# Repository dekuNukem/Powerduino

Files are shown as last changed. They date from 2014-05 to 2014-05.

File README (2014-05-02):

Powerduino - A fully programmable power strip with energy monitoring and wireless connectivity

A short introduction video: https://www.youtube.com/watch?v=ZPqnHy5OSVQ

Powerduino is a power strip that has been enhanced with a Teensy 3.1 microcontroller, RTC, current sensors, relays, WiFi module, external digital/analog IO pins, LCD, SD card, USB connector, and buttons. With an arsenal of new sensors and components, along with its open source design and Arduino compatible microcontroller, users are able to wirelessly control and monitor each socket over WiFi, observe real-time current, power and energy consumption of individual sockets, perform energy usage logging on SD card, and upload custom programs to the power strip through Arduino IDE to perform any action they want on each socket.

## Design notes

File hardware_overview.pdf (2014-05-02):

# Powerduino Hardware Overview

Xinao Wang
Adrian Beltran
Ronald Meyer
hammondmay@gmail.com

### Contents

1. Project Overview | 1 |
2. Design | 2 |
2.1 Block Diagram | 2 |
2.2 Circuit Overview | 3 |
2.2.1 Power Supply | 3 |
2.2.2 Relay Board with Current Sensor | 3 |
2.2.3 Main Board | 3 |
2.2.4 Front Panel | 4 |
2.3 Part List | 5 |
3. Project Gallery | 6 |
4. References | 8 |

### 1. Project Overview

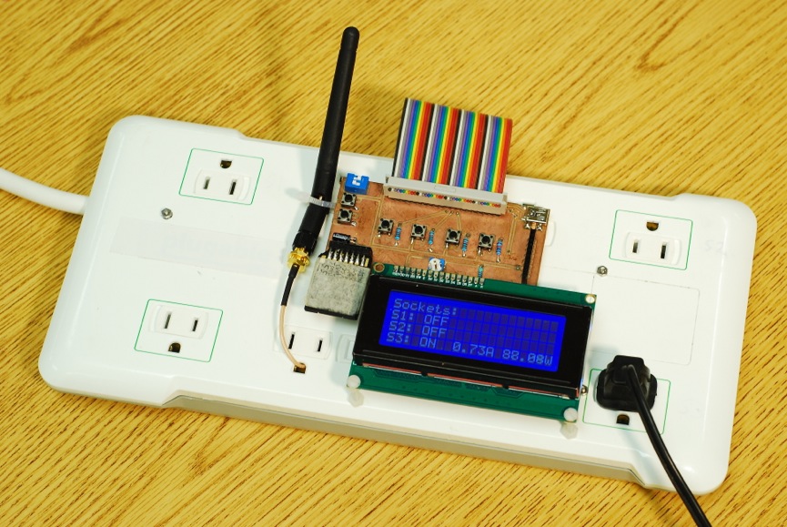
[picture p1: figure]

Powerduino is a power strip that has been enhanced with a Teensy 3.1 microcontroller, RTC, current sensors, relays, WiFi module, external digital/analog IO pins, LCD, SD card, USB connector, and buttons. With an arsenal of new sensors and components, along with its open source design and Arduino compatible microcontroller, users are able to wirelessly control and monitor each socket over WiFi, observe real-time current, power and energy consumption of individual sockets, perform energy usage logging on SD card, and upload custom programs to the power strip through Arduino IDE to perform any action they want on each socket. This enables a wide range of new applications within energy saving, safe and fast mains voltage home automation, and more.

For example, one can create an automatic lamp that turns on in the night by attaching a light sensor to one of the external pins, writing 4 lines of code, and plugging in a regular lamp in the designated socket. Similarly, with just a thermocouple, one can write a program to turn a $20 mini-oven into a reflow oven without modifying it in any way and being exposed to dangerous mains voltage. Want to turn off a socket when it has used more than 1kWh of power? Schedule a socket based on time? Limit the current that a socket can use? Implement a light dimmer right in the power strip? If you can code it, Powerduino can do it.

### 2. Design

### 2.1 Block Diagram

The construction of Powerduino is relatively straightforward, with microcontroller, WiFi module, power supply, and relay boards inside the power strip, and a front panel outside the power strip. A 2-row 40-pin ribbon cable connecting connecting them together.

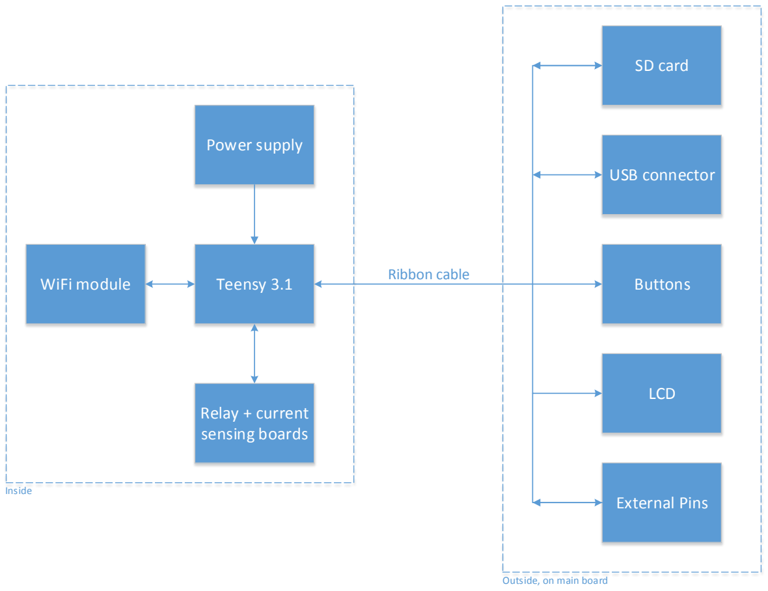
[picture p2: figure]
Teensy 3.1; Relay + current sensing boards; Power supply; WiFi module; SD card; USB connector; Buttons; LCD; External Pins; Ribbon cable; Inside; Outside, on main board

Figure 1. High-level block diagram

### 2.2 Circuit Overview

Please refer to corresponding Eagle file while reading the descriptions.

### 2.2.1 Power Supply

A simple linear power supply was designed for this project. The transformer(FP16-150) steps mains voltage down to 8V, which is then bridge rectified and regulated to provide 5V and 3.3V for various components. The half-wave of transformer’s output have also been divided down to within 3.3V, intended for microcontroller’s ADC, for zero-crossing detection. 400mA resettable fuses was used for protection. I only had 200mA fuses so I put two in parallel.

Feel free to use one of those miniature switch-mode 5V USB power supply in phone chargers, since it would be smaller than this design, and also more efficient. However you do need to implement your own 3.3V source and zero-crossing detection solution(if you need it).

### 2.2.2 Relay Board with Current Sensor

The relay board with current sensor is used to control each socket, as well as providing microcontroller with the information of how much current is passing through the relay. Two types of relay boards were designed for this project, namely solid state and mechanical.

The solid state relay was constructed with a MAC224 TRIAC controlled by a MOC3010 TRIAC driver. It provides very fast switching time, and noiseless operation. However, the TRIAC does generate a substantial amount of heat during operation, as much as around 9W when switching 10A of current. So adequate cooling is required if solid state relay are to be used continuously inside the confined space of an power strip.

The mechanical relay board is essentially the same as solid state relay board, apart from using a mechanical relay, in this case a T77S1D10-05. It produces much less heat when switching high currents compared to traic, but does produce some noise, along with slower switching times.

Both type of relay board contains a ACS712 Hall Effect current sensor to measure current. When no current is present, the output is 2.5V, while output is greater than 2.5V for current in one direction, and smaller than 2.5V in the other direction. The 0-5V output was divided down to 0-3.3V using a resistor divider for Teensy’s ADC.

When assembling the relay board, make sure to insulate vertical resistors with heat shrink tubing to prevent them from touching and shorting out.

A LED can be connected to the 2-pin header at the bottom right corner of each board, which will light up when relay is on.

### 2.2.3 Main Board

The main board houses the microcontroller, WiFi module, 3V coin battery holder for the real-time clock, and various connectors to other modules, namely power supply, relay boards, and face panel.

The reset signal is a test point on Teensy 3.1, so solder a wire on it and connect the other end to the single TEENSY_RESET header near the top right of the PCB.

To use the USB connector on the front panel for uploading program, cut a micro-usb cable, plug the micro-usb side into teensy, and connect D+, D- and Vusb wires to the headers on the PCB.

Do not use 80-wire IDE cable as a ribbon cable to connect Main Board and Front Panel, some pins in the IDE cable are electrically connected together.

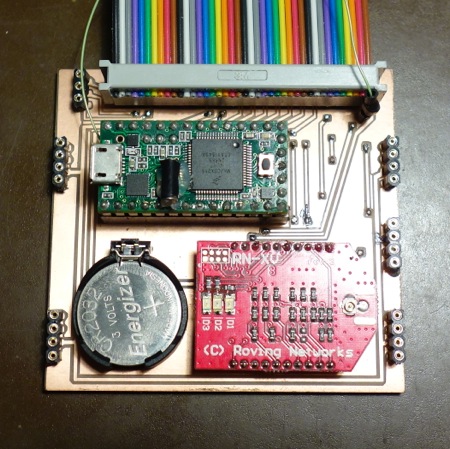
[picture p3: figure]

Figure 2. Main board

### 2.2.4 Front Panel

The front panel is located at the front of the power strip. It contains user-interface related components for the ease of use, namely LCD, buttons, SD card, external pins, mini-USB connector, as well as the connector to the main board inside.

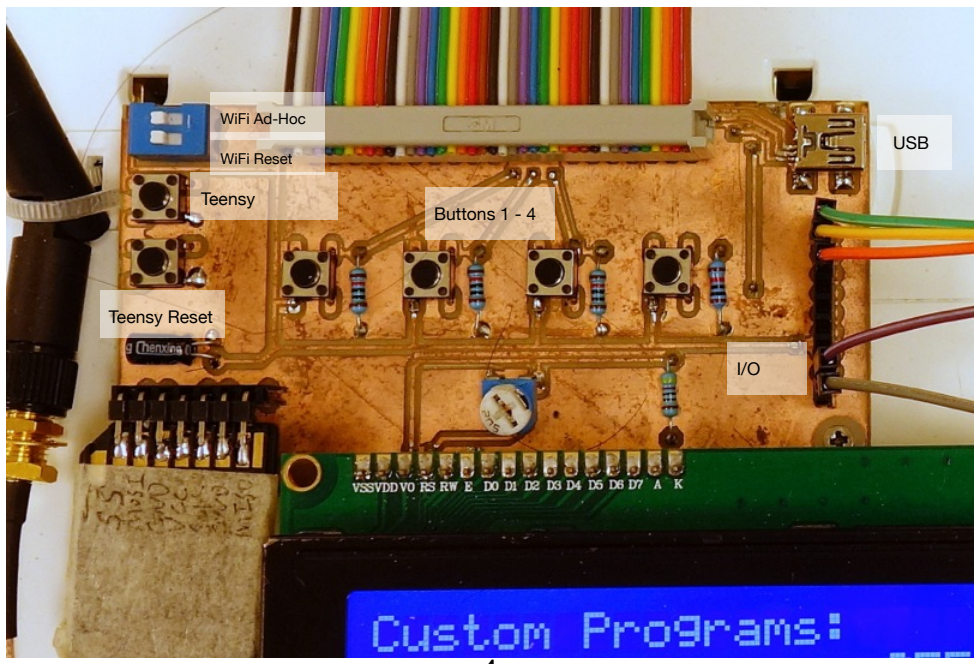
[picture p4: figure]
Buttons 1 - 4 Teensy; Teensy Reset; USB; WiFi Ad-Hoc; WiFi Reset

Figure 3. Front Panel

### 2.3 Part List

For those parts with a link to the product page, you don’t have to buy it there, just make sure the part you get is the same.

Description | Part Number | Notes
WiFi module | RN-XV WiFly | https://www.sparkfun.com/products/10822
Power strip | Plugable 12 Outlet Power Surge Protector | Purchased from Amazon (http://www.amazon.com/Plugable-Protector-Charging-Samsung-Devices/dp/B00CHRID4Y?s=electronics)
LCD | 20*4 | https://www.sparkfun.com/products/256
SD card | | Solder male pin header on Micro SD adaptor, plug into female pin header on front panel. The gold contact side facing buttons.
Microcontroller | Teensy 3.1
TRIAC | MAC224 | If you decide to use solid state relay board
TRIAC Driver | MOC3010 | If you decide to use solid state relay board
Mechanical relay | T77S1D10-05 | If you decide to use mechanical relay board
Pushbuttons | | https://www.sparkfun.com/products/97
2-Bit DIP switch | | http://i.imgur.com/cVnSq95.jpg

Assorted resistors

Assorted capacitors

Assorted pin headers

Assorted wires | | Including 40-wire ribbon cable
Resettable fuse | 500mA
Coin battery holder | | https://www.sparkfun.com/products/783
Mini-USB connector | | https://www.sparkfun.com/products/587
Transformer | TP16-150
Diode bridge | W02G
Voltage Regulators | 7805, 7833

### 3. Project Gallery

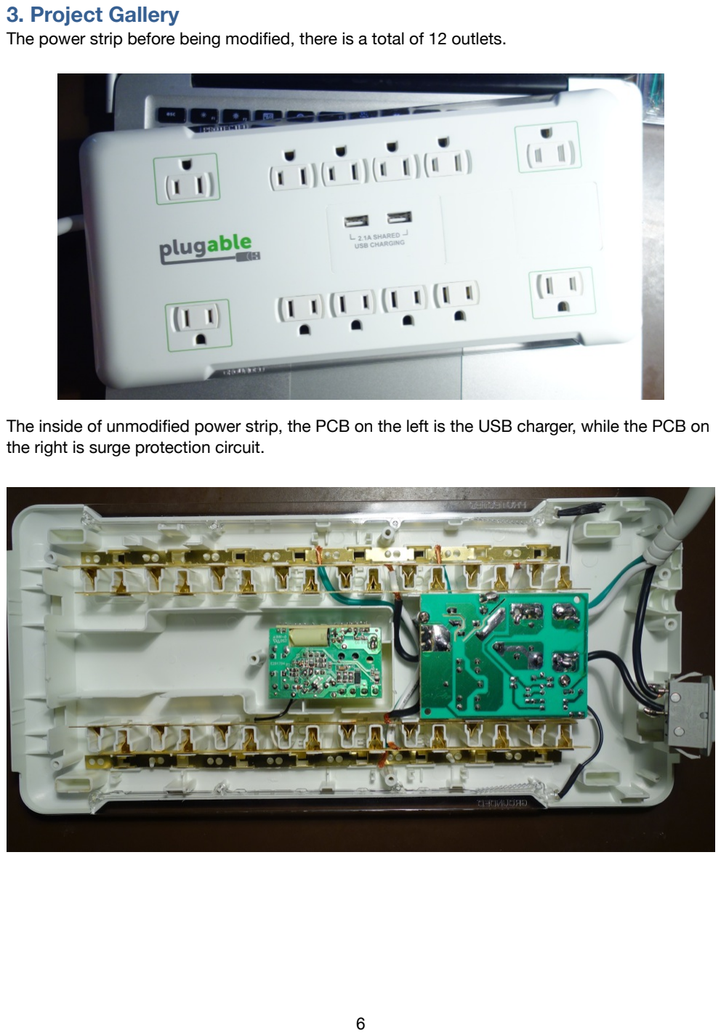
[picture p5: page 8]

The power strip before being modified, there is a total of 12 outlets.

The inside of unmodified power strip, the PCB on the left is the USB charger, while the PCB on the right is surge protection circuit.

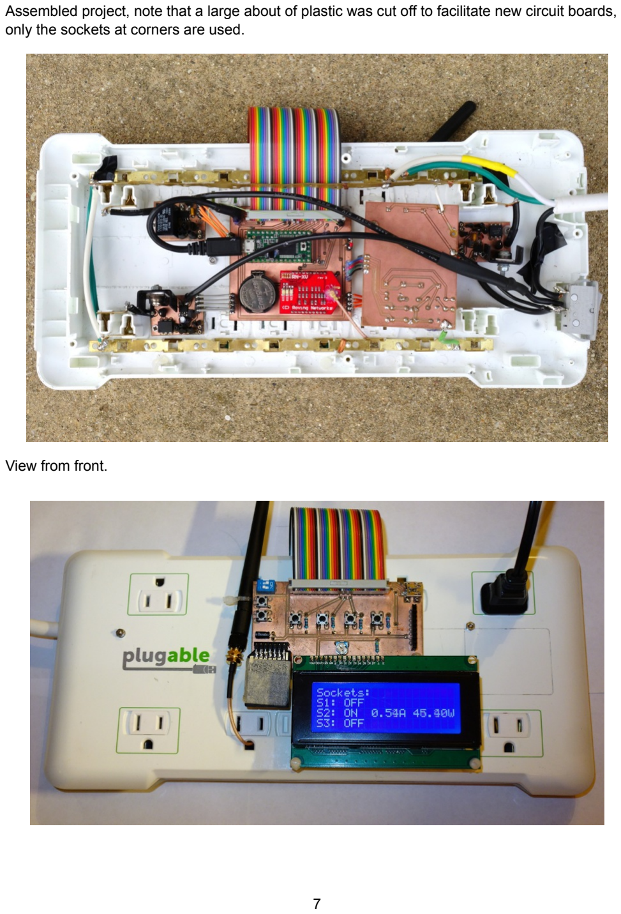
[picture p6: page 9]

Assembled project, note that a large about of plastic was cut off to facilitate new circuit boards, only the sockets at corners are used.

View from front.

### 4. References

[1] ACS712 Fully Integrated, Hall Effect-Based Linear Current Sensor with 2.1 kVRMS Voltage Isolation and a Low-Resistance Current Conductor, Allegro Microsystems, Inc., Worcester, MA, 2007.
[2] Application Note AN-3003, Applications of Non Zero Crossing TRIAC Drivers Featuring the MOC3011, Fairchild Semiconductor Corporation, 2003.

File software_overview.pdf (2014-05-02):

# Powerduino Software Overview

Xinao Wang
Adrian Beltran
Ronald Meyer
hammondmay@gmail.com

### Contents

1. Flow charts | 1 |
1.1 PC software flow chart | 1 |
1.2 Microcontroller software flow chart | 2 |
2. Functionality overview | 3 |
2.1 Communication protocol | 3 |
2.1.1 Master commands | 3 |
2.1.2 Slave commands | 3 |
2.1.3 Existing command pairs | 4 |
2.1.3.1 Set time | 4 |
2.1.3.2 Request energy usage | 4 |
2.1.3.3 Toggle socket | 4 |
2.1.3.4 Request socket status | 5 |
2.2 File structure | 5 |
2.2.1 Energy logging file | 5 |
2.2.1 Setting and states file | 6 |
2.3 Current measurement | 6 |
2.3.1 RMS current calculation | 6 |
2.3.1 Moving average smoothing | 7 |

### 1. Flow charts

### 1.1 PC software flow chart

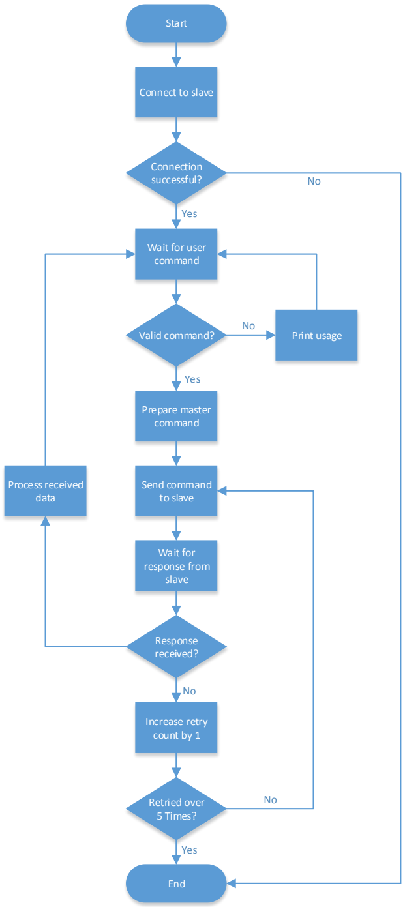
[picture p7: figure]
Start; Connect to slave; Wait for user command; Valid command?; Print usage No; Prepare master command; Yes; Send command to slave; Wait for response from slave; Connection successful?; End; Response received?; Retried over 5 Times?; Increase retry count by 1; Process received data

Figure 1. Flow chart for PC program

### 1.2 Microcontroller software flow chart

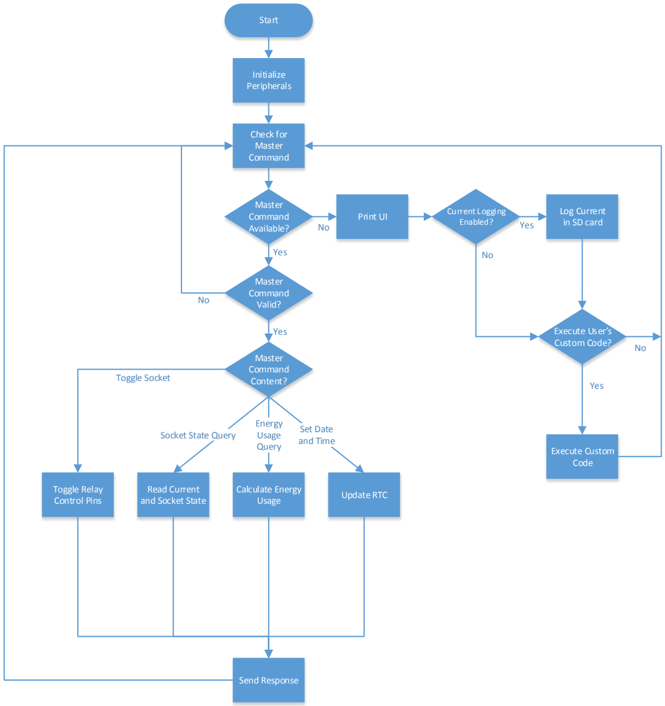
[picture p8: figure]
Start; Check for Master Command; Initialize Peripherals; Master Command Available?; Yes; Master Command Valid?; Master Command Content?; Calculate Energy Usage; Read Current; and Socket State; Update RTC Toggle Relay; Control Pins; Toggle Socket; Socket State Query; Energy Usage Query; Set Date and Time; Send Response; Log Current in SD card; Current Logging; Enabled? No; Execute User’s Custom Code?; Execute Custom Code; Print UI

Figure 2. Flow chart for microcontroller program

### 2. Functionality overview

### 2.1 Communication protocol

The communication protocol of this project is relatively straightforward. PC program send commands over WiFi network, and microcontroller receives and responds to PC command via the WiFi module over serial.

To ensure the power strip receives PC’s command, a Stop-and-wait protocol was used. Each time PC sends a command, it waits until acknowledgement from power strip is received, otherwise the command will be sent again after timeout.

### 2.1.1 Master commands

Master commands (commands generated from PC) always starts with a 2-byte header. The first byte of the header is always MASTER_COMMAND_TRANSMISSION_START, followed by the number of bytes of data to be sent to slave(power strip).

Figure 3. Master command structure

### 2.1.2 Slave commands

Slave commands (Microcontroller’s response to master commands) is structurally similar to master commands, with a 2-byte header followed by data. Except the first byte in the header is SLAVE_COMMAND_ACK.

Figure 4. Slave command structure

MASTER_COMMAND_TRANSMISSION_START

Data Length

Data

SLAVE_COMMAND_ACK

Data Length

Data

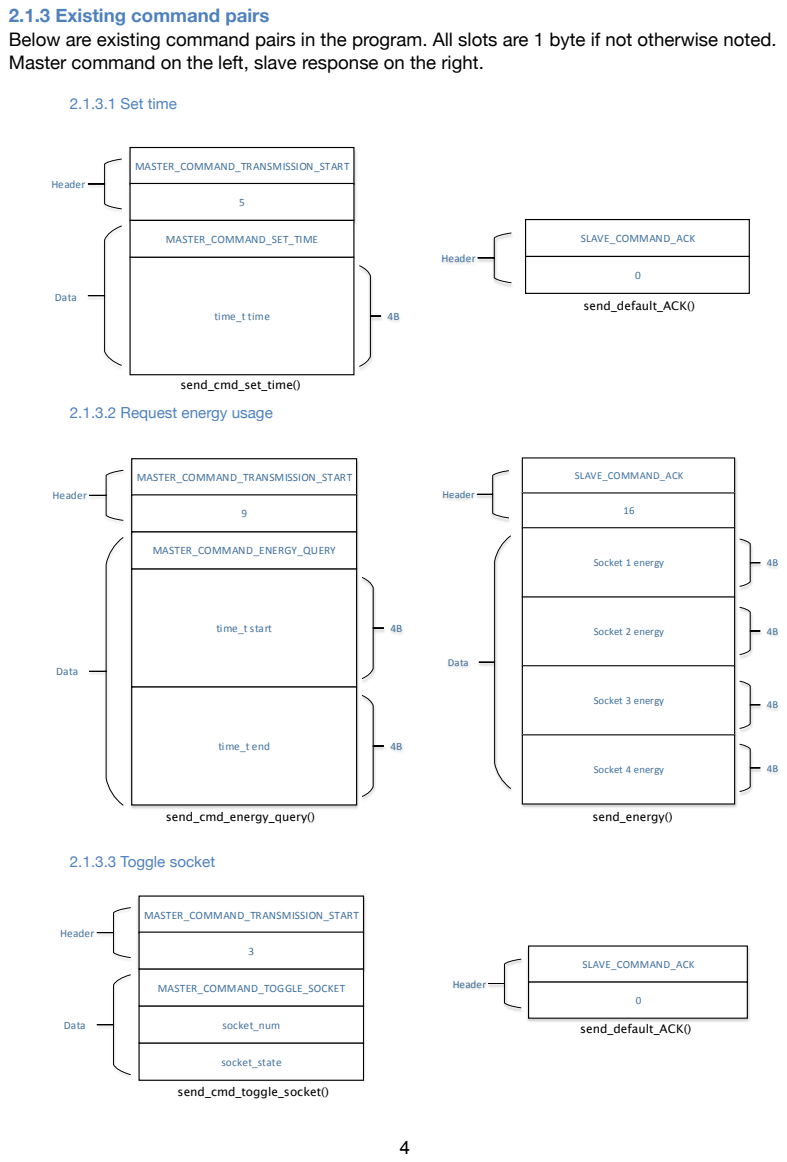
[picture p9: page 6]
2.1.3.1 Set time; 2.1.3.3 Toggle socket; Data; Header; MASTER_COMMAND_TRANSMISSION_START; MASTER_COMMAND_ENERGY_QUERY; time_t start; time_t end; SLAVE_COMMAND_ACK; _START; _QUERY; MASTER_COMMAND_TOGGLE_SOCKET; socket_num; socket_state; MASTER_COMMAND_SET_TIME; time_t time; send_cmd_set_time(); send_default_ACK(); send_cmd_energy_query(); send_energy(); send_cmd_toggle_socket()

2.1.3 Existing command pairs
Below are existing command pairs in the program. All slots are 1 byte if not otherwise noted.
Master command on the left, slave response on the right.

MASTER_COMMAND_TRANSMISSION_START

2.1.3.2 Request energy usage

Socket 1 energy

Socket 2 energy

Socket 3 energy

Socket 4 energy

2.1.3.4 Request socket status

where socket_status byte in slave response is constructed as follows:

### 2.2 File structure

The microcontroller program uses SD card for data logging and storing settings and states. The file structures are described below.

2.2.1 Energy logging file
The program stores the current reading of each socket to SD card every 10 seconds. The program will try to open a file with the name of that particular day, for example, if today is April 30th 2014, it will try to open a log file named 20140430, or create one if it doesn’t exist.

Each entry is then appended to the end of the file in little endian, with the following structure:

See append_current_log() for implementation.

Data

MASTER_COMMAND_TRANSMISSION_START

1

MASTER_COMMAND_REQUEST_SOCKET_STATUS

Header

SLAVE_COMMAND_ACK

9

socket_status

current_array_global[0]

current_array_global[1]

current_array_global[2]

current_array_global[3]

Data

Header

2B

2B

2B

2B

0 | 0 | S4 state

S3
state

S2
state

S1
state 0 | 0
7 | 0

send_cmd_request_socket_status()

send_socket_status()

Unix timestamp | S1 current | S2 current | S3 current | S4 current
4B | 2B | 2B | 2B | 2B

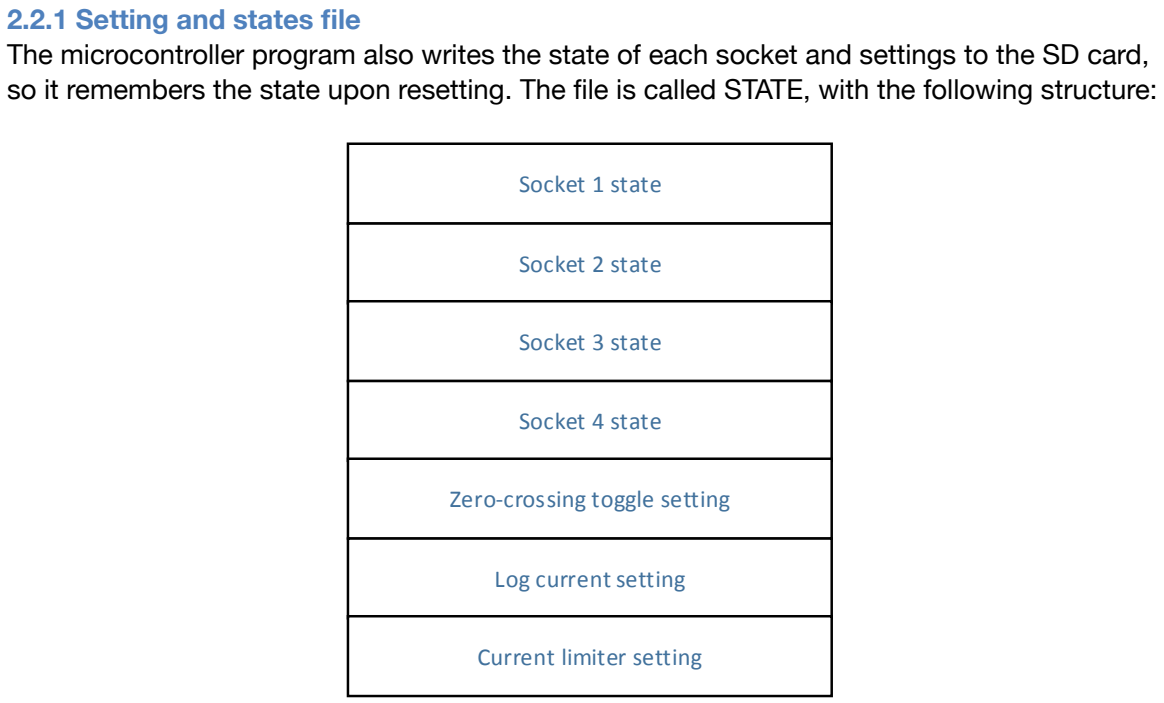
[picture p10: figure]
2.2.1 Setting and states file; Socket 1 state; Socket 2 state; Socket 3 state; Socket 4 state; Zero-crossing toggle setting; Log current setting; Current limiter setting

The microcontroller program also writes the state of each socket and settings to the SD card, so it remembers the state upon resetting. The file is called STATE, with the following structure:

Each slot is one byte, starting from the beginning of the file. See save_state() and recover_state() for implementation.

### 2.3 Current measurement

### 2.3.1 RMS current calculation

The output of current sensor is centered around 2.5V. When no current is present the output is 2.5V, output is greater than 2.5V for current in one direction, and smaller than 2.5V in the other direction. The current sensor output (0 - 5V) is divided down to 0 - 3.3V using a resistor divider. Therefore, the current sensor reading is centered around 1.6V after the division.

The resolution of Teensy's on-board ADC is 13 bits, meaning it reads 0V as 0 and 3.3V as 8192.

Each time read_current function is called, it takes 83 samples of current sensor reading in 200 microsecond interval, which is a total of 16600 microseconds, which is the period of a single 60Hz cycle (1/60 = 16.6 ms = 16666 us).

The samples are symmetrical around 1.6V, which is 8192 / 2 = 4096. To calculate RMS value, each sample is subtracted the average of entire sample array to make it center around 0, then the standard RMS method is used, taking the square root of the arithmetic mean of the squares of sample values.

The result RMS is still not current, but just the voltage reading from current sensor, to obtain current reading, a linear formula is applied, calculated from current sensor's datasheet.

I = ((4096 + RMS_value) / 8192) * 50 - 25

The resulting current is a floating number, to save space and make it easy to store on SD card and transport over serial, the float value is multiplied 1000 then stored as a 16-bit unsigned integer. For example if the result is 0.45A, 0.45 * 1000 = 450, so 450 is stored. The largest current can be stored in an int16_t is 65535 / 1000 = 65.535A, well over our current sensor’s 20A maximum rating.

This method uses quite a lot of memory and has a 17ms delay every time it’s called. Feel free to improve it, see current_reader class for implementation.

A timer interrupt fires every 0.3 seconds to call read_current function, and store the current reading in a global 4-element array, one for each socket. When a current reading is needed, the program will read the value from the array.

### 2.3.1 Moving average smoothing

However, the result of above method tend to fluctuate around the true reading, in order to achieve a smoother readout, each new current reading is taken average with 9 previous readings.

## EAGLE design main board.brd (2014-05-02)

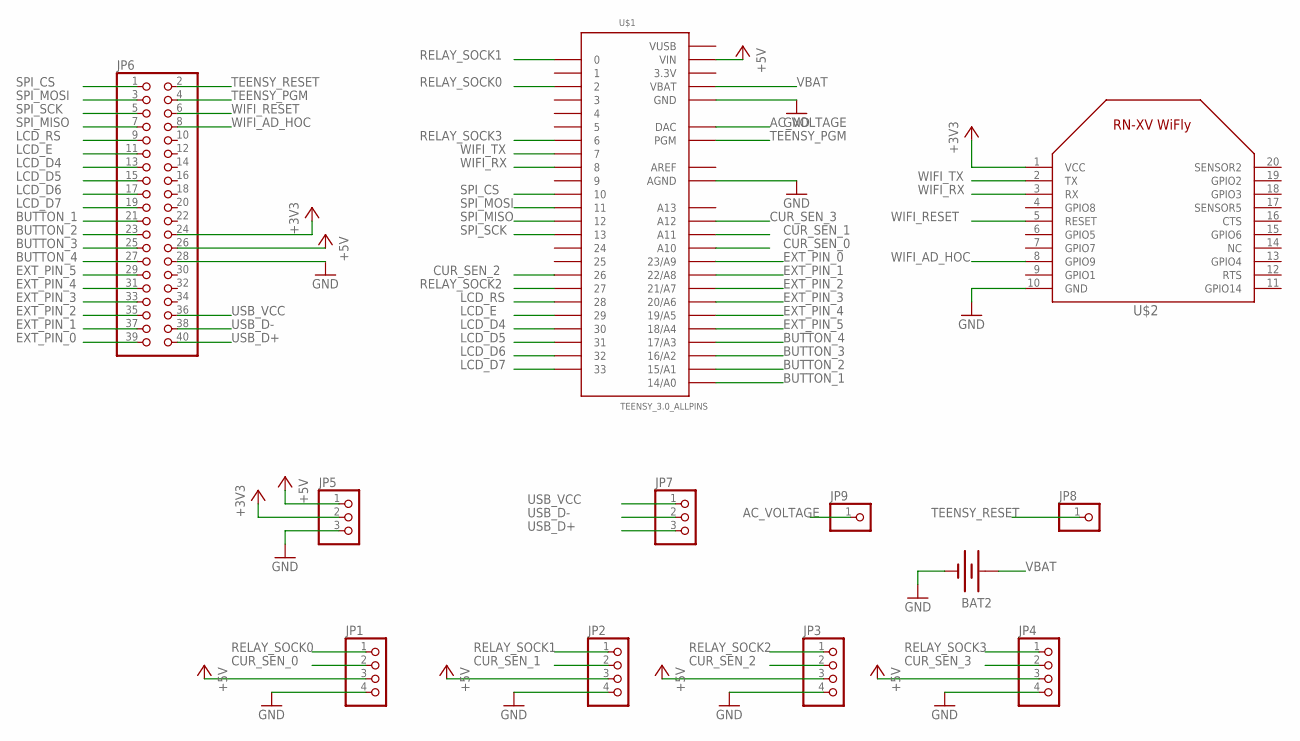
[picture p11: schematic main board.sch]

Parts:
BAT2: BATTERY20PTH; BATTCOM_20MM_PTH
JP1, JP2, JP3, JP4: PINHD-1X4/90; 1X04/90
JP5: PINHD-1X3/90; 1X03/90
JP6: PINHD-2X20; 2X20
JP7: PINHD-1X3; 1X03
JP8, JP9: PINHD-1X1; 1X01
U$1: TEENSY_3.0_ALLPINS
U$2: XBEEWIFLY; XBEE

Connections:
3.3V: U$1.3.3V, U$1.3.3V1 (3.3V), U$1.3.3V2 (3.3V)
+3V3: JP5.2, JP6.24, U$2.1 (VCC)
+5V: JP1.3, JP2.3, JP3.3, JP4.3, JP5.1, JP6.26, U$1.VIN
AC_VOLTAGE: JP9.1, U$1.RESET (DAC)
AREF: U$1.AREF
BUTTON_1: JP6.21, U$1.14/A0
BUTTON_2: JP6.23, U$1.15/A1
BUTTON_3: JP6.25, U$1.16/A2
BUTTON_4: JP6.27, U$1.17/A3
CUR_SEN_0: JP1.2, U$1.A10
CUR_SEN_1: JP2.2, U$1.A11
CUR_SEN_2: JP3.2, U$1.26
CUR_SEN_3: JP4.2, U$1.A12
EXT_PIN_0: JP6.39, U$1.23/A9
EXT_PIN_1: JP6.37, U$1.22/A8
EXT_PIN_2: JP6.35, U$1.21/A7
EXT_PIN_3: JP6.33, U$1.20/A6
EXT_PIN_4: JP6.31, U$1.19/A5
EXT_PIN_5: JP6.29, U$1.18/A4
GND: BAT2.2 (-), JP1.4, JP2.4, JP3.4, JP4.4, JP5.3, JP6.28, U$1.AGND, U$1.GND, U$1.GND1 (GND), U$1.GND2 (GND), U$2.10 (GND)
LCD_D4: JP6.13, U$1.30
LCD_D5: JP6.15, U$1.31
LCD_D6: JP6.17, U$1.32
LCD_D7: JP6.19, U$1.33
LCD_E: JP6.11, U$1.29
LCD_RS: JP6.9, U$1.28
RELAY_SOCK0: JP1.1, U$1.2
RELAY_SOCK1: JP2.1, U$1.0
RELAY_SOCK2: JP3.1, U$1.27
RELAY_SOCK3: JP4.1, U$1.6
SPI_CS: JP6.1, U$1.10
SPI_MISO: JP6.7, U$1.12
SPI_MOSI: JP6.3, U$1.11
SPI_SCK: JP6.5, U$1.13
TEENSY_PGM: JP6.4, U$1.PGM
TEENSY_RESET: JP6.2, JP8.1
USB_D+: JP6.40, JP7.3
USB_D-: JP6.38, JP7.2
USB_VCC: JP6.36, JP7.1
VBAT: BAT2.1 (+), U$1.VBAT
VUSB: U$1.VUSB
WIFI_AD_HOC: JP6.8, U$2.8 (GPIO9)
WIFI_RESET: JP6.6, U$2.5 (RESET)
WIFI_RX: U$1.8, U$2.3 (RX)
WIFI_TX: U$1.7, U$2.2 (TX)

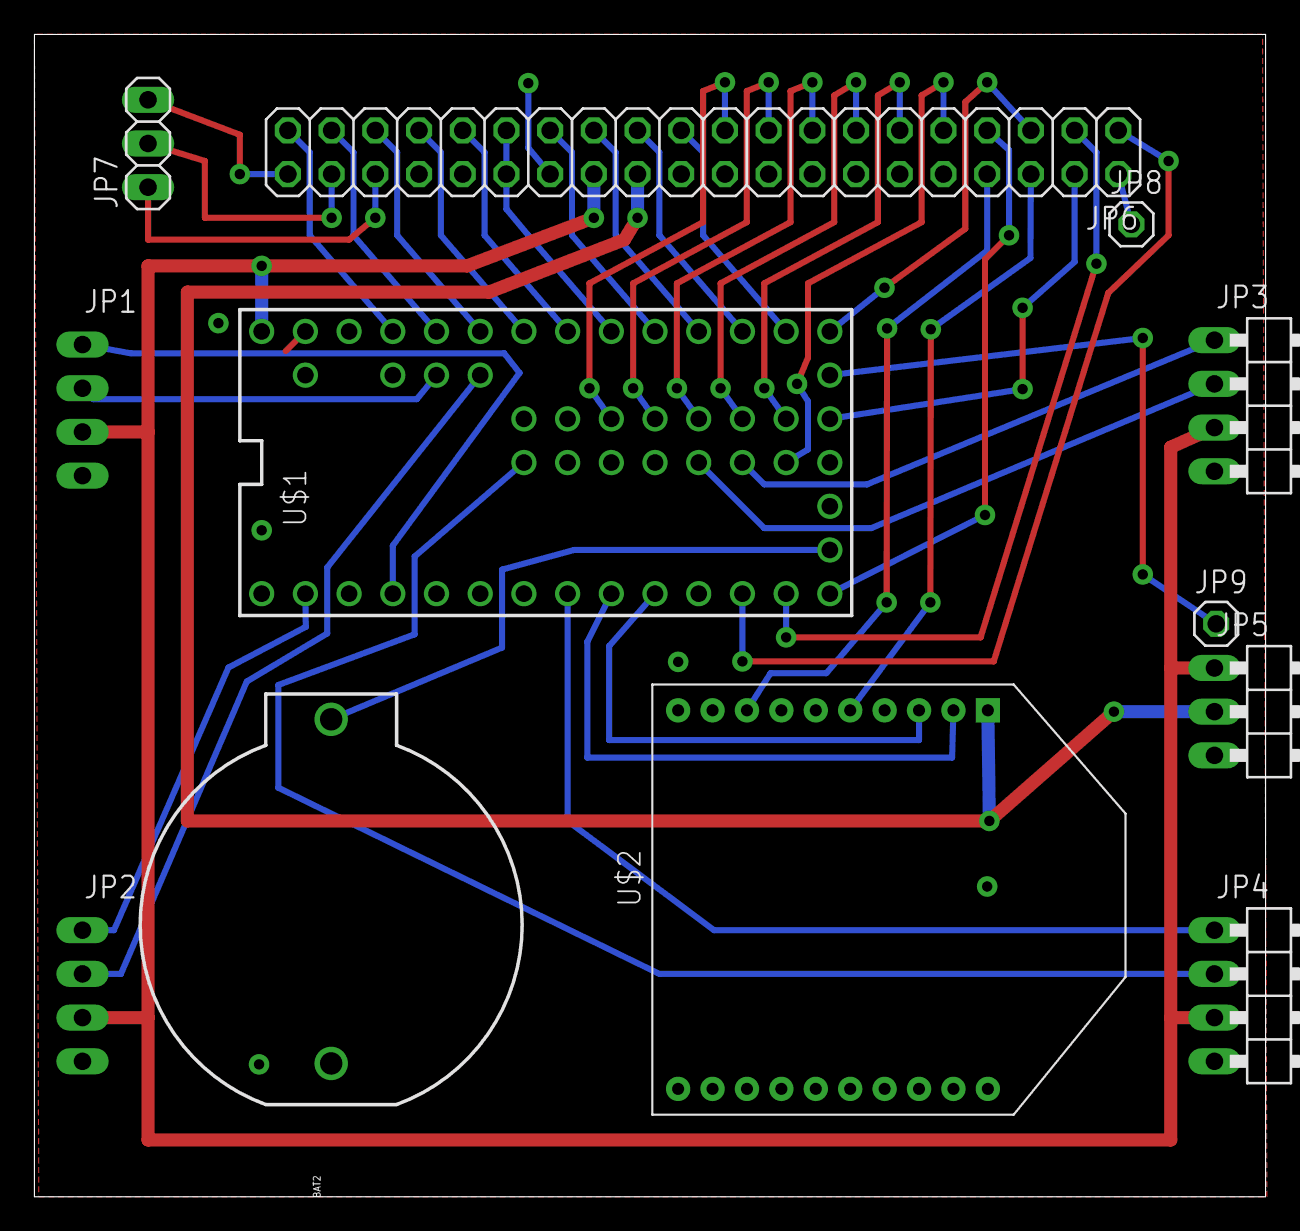
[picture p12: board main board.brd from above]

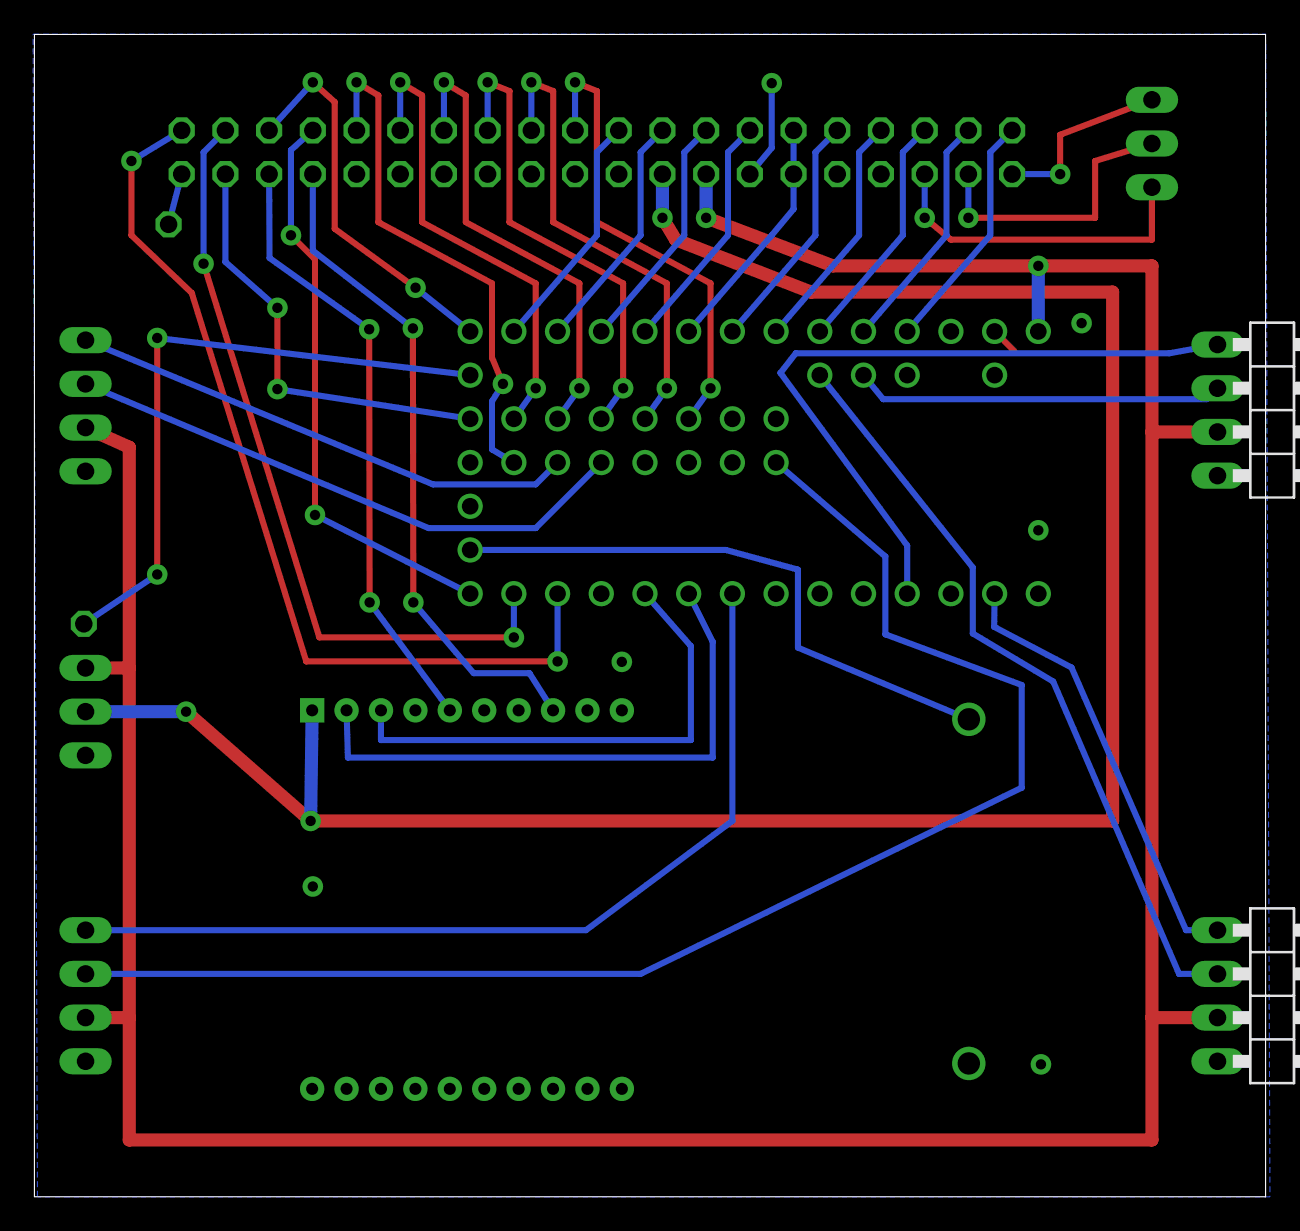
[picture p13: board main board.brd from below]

Board: 2 copper layers, 71.6 x 67.6 mm, 12 parts (2 on the bottom side), 43 nets.

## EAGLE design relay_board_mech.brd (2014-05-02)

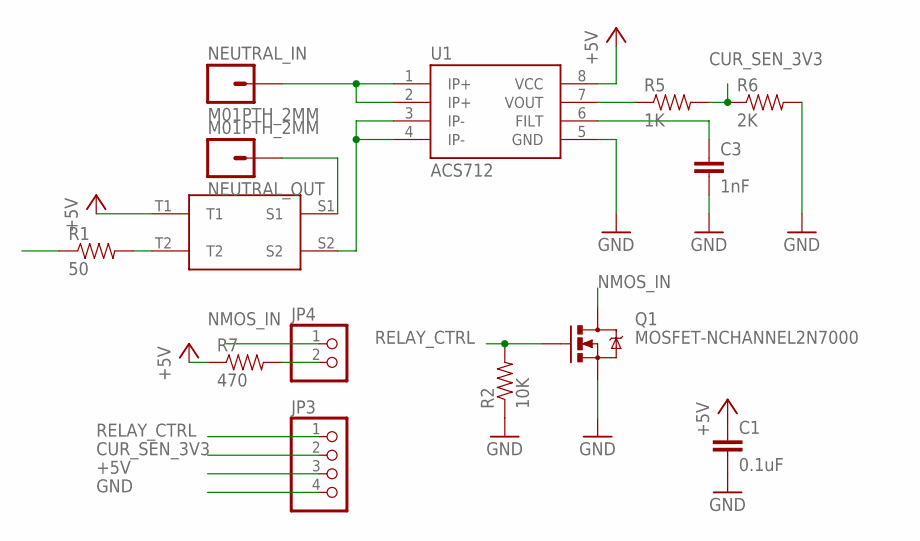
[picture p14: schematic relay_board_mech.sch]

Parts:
C1: 0.1uF; CAP-PTH-SMALLEZ
C3: 1nF; CAP-PTH-SMALLEZ
JP3: PINHD-1X4; 1X04
JP4: PINHD-1X2; 1X02
NEUTRAL_IN: M01PTH_2MM; 1X01_2MM
NEUTRAL_OUT: M01PTH_2MM; 1X01_2MM
Q1: MOSFET-NCHANNEL2N7000; TO-92
R1: 50; AXIAL-0.1
R2: 10K; AXIAL-0.1
R5: 1K; AXIAL-0.1
R6: 2K; AXIAL-0.1
R7: 470; AXIAL-0.1
U1: ACS712; SO08
U$1: T77S1D10-05

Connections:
+5V: C1.1, JP3.3, R7.P$1 (1), U1.8 (VCC), U$1.T1
CUR_SEN_3V3: JP3.2, R5.P$2 (2), R6.P$1 (1)
CUR_SEN_5V: R5.P$1 (1), U1.7 (VOUT)
GND: C1.2, C3.2, JP3.4, Q1.1 (S), R2.P$1 (1), R6.P$2 (2), U1.5 (GND)
unnamed: NEUTRAL_OUT.1, U$1.S1
unnamed: R1.P$2 (2), U$1.T2
unnamed: C3.1, U1.6 (FILT)
unnamed: NEUTRAL_IN.1, U1.1 (IP+), U1.2 (IP+)
unnamed: JP4.2, R7.P$2 (2)
unnamed: U1.3 (IP-), U1.4 (IP-), U$1.S2
NMOS_IN: JP4.1, Q1.3 (D), R1.P$1 (1)
RELAY_CTRL: JP3.1, Q1.2 (G), R2.P$2 (2)

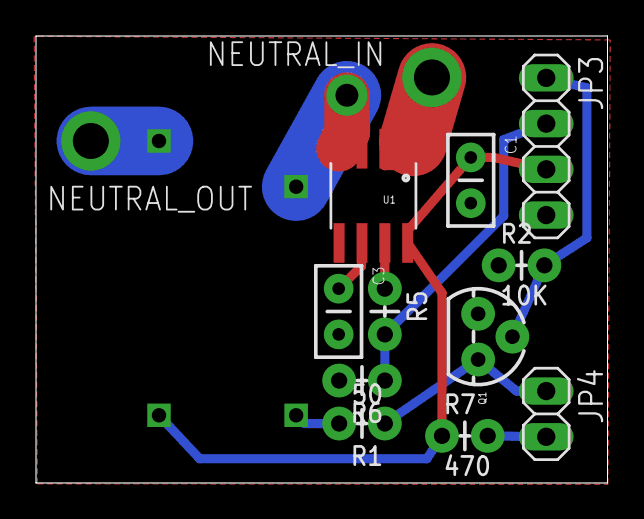
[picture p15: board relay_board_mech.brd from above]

Board: 2 copper layers, 31.8 x 24.8 mm, 14 parts (0 on the bottom side), 12 nets.

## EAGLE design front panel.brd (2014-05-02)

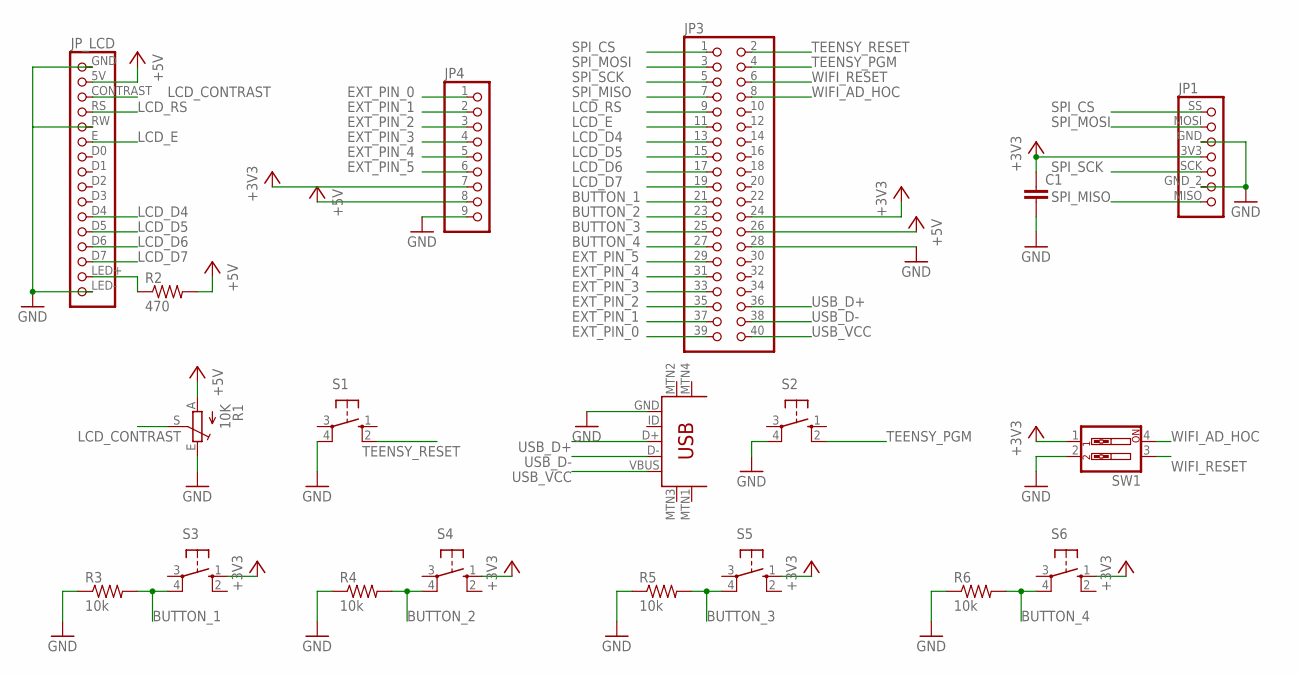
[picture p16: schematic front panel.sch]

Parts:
C1: 0.1UF-50V-20%(PTH)KIT-EZ; CAP-PTH-SMALL-KIT
JP1: PINHD-1X7; 1X07
JP3: PINHD-2X20; 2X20
JP4: PINHD-1X9; 1X09
JP_LCD: PINHD-1X16; 1X16
R1: 10K; CA6V
R2: 470; 0207/10
R3, R4, R5, R6: 10k; 0207/10
S1, S2, S3, S4, S5, S6: 10-XX; B3F-10XX
SW1: SW_DIP-2; EDG-02
U$1: USB-MINIB-5PIN; USB-MINIB

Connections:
+3V3: C1.1, JP1.3V3 (4), JP3.24, JP4.7, S3.1 (S), S4.1 (S), S5.1 (S), S6.1 (S), SW1.1
+5V: JP3.26, JP4.8, JP_LCD.5V, R1.A, R2.2
BUTTON_1: JP3.21, R3.2, S3.4 (P1)
BUTTON_2: JP3.23, R4.2, S4.4 (P1)
BUTTON_3: JP3.25, R5.2, S5.4 (P1)
BUTTON_4: JP3.27, R6.2, S6.4 (P1)
EXT_PIN_0: JP3.39, JP4.1
EXT_PIN_1: JP3.37, JP4.2
EXT_PIN_2: JP3.35, JP4.3
EXT_PIN_3: JP3.33, JP4.4
EXT_PIN_4: JP3.31, JP4.5
EXT_PIN_5: JP3.29, JP4.6
GND: C1.2, JP1.GND (3), JP1.GND_2 (6), JP3.28, JP4.9, JP_LCD.GND, JP_LCD.LED-, JP_LCD.RW, R1.E, R3.1, R4.1, R5.1, R6.1, S1.4 (P1), S2.4 (P1), SW1.2, U$1.GND
LCD_CONTRAST: JP_LCD.CONTRAST, R1.S
LCD_D4: JP3.13, JP_LCD.D4
LCD_D5: JP3.15, JP_LCD.D5
LCD_D6: JP3.17, JP_LCD.D6
LCD_D7: JP3.19, JP_LCD.D7
LCD_E: JP3.11, JP_LCD.E
LCD_RS: JP3.9, JP_LCD.RS
unnamed: JP_LCD.LED+, R2.1
SPI_CS: JP1.SS (1), JP3.1
SPI_MISO: JP1.MISO (7), JP3.7
SPI_MOSI: JP1.MOSI (2), JP3.3
SPI_SCK: JP1.SCK (5), JP3.5
TEENSY_PGM: JP3.4, S2.2 (S1)
TEENSY_RESET: JP3.2, S1.2 (S1)
USB_D+: JP3.36, U$1.D+
USB_D-: JP3.38, U$1.D-
USB_VCC: JP3.40, U$1.VBUS
WIFI_AD_HOC: JP3.8, SW1.4
WIFI_RESET: JP3.6, SW1.3

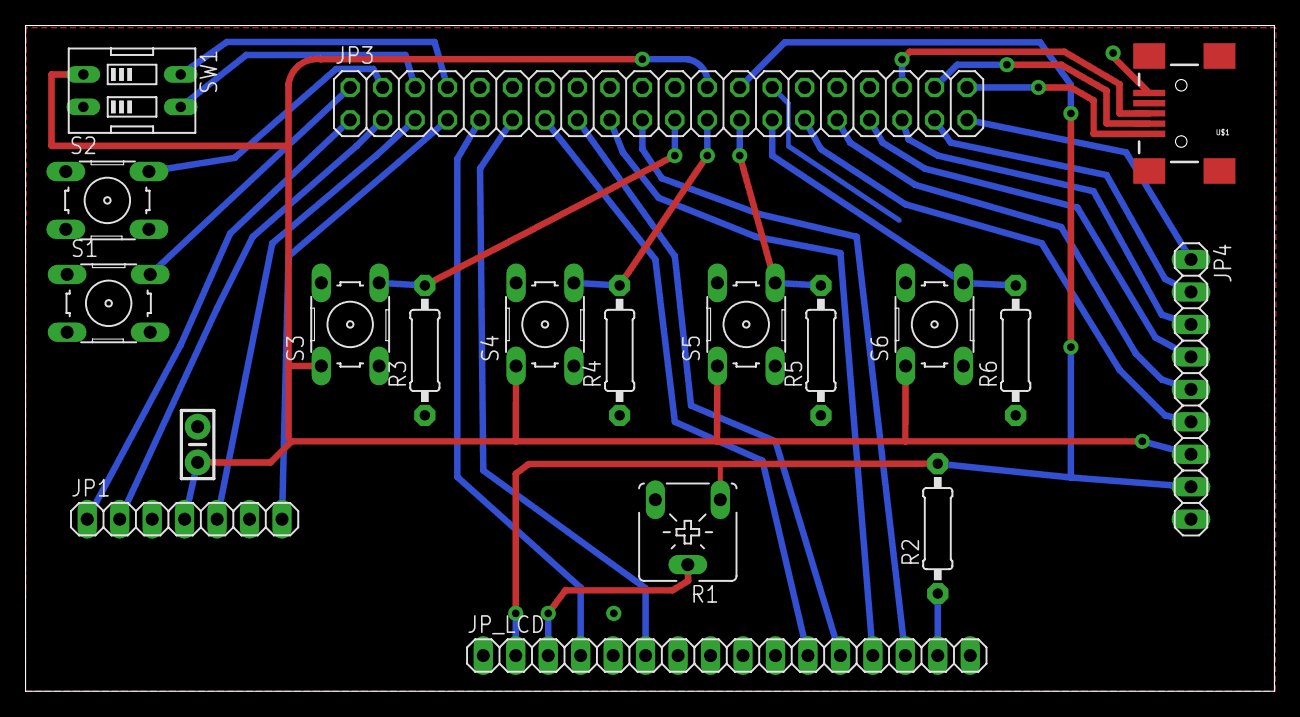
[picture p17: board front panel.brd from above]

Board: 2 copper layers, 97.7 x 52.1 mm, 19 parts (0 on the bottom side), 32 nets.

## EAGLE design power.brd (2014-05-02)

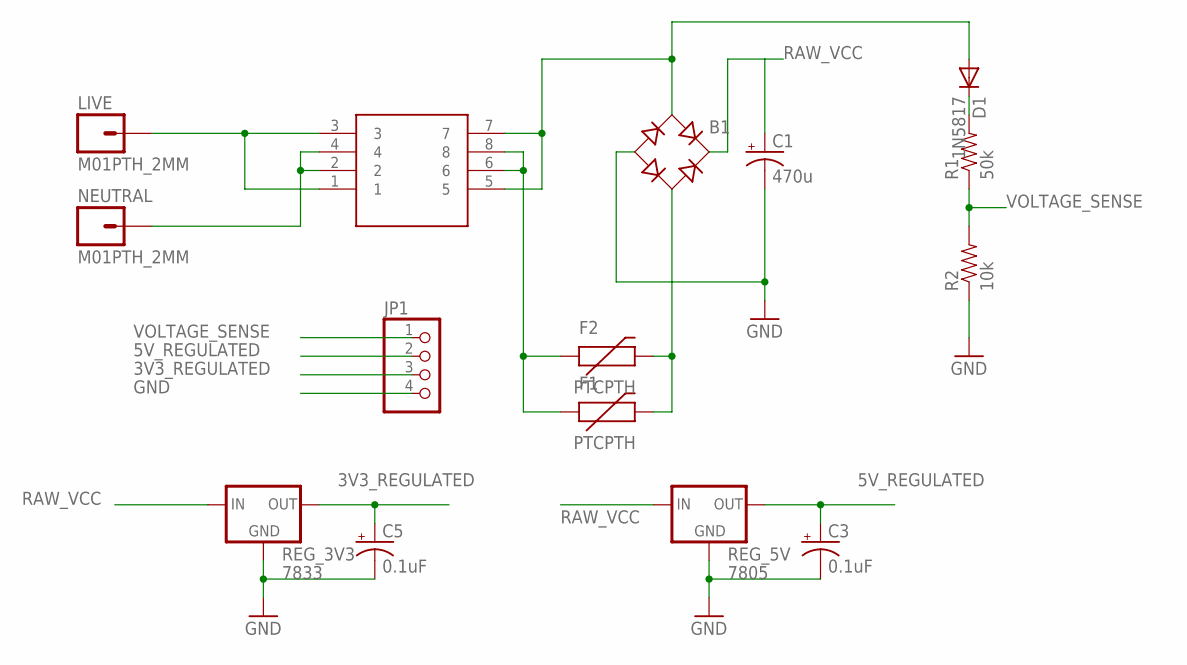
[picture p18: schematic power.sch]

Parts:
B1: RB1A
C1: 470u; E3,5-8
C3, C5: 0.1uF; CPOL-RADIAL-10UF-25V
D1: 1N5817; DO34-7
F1, F2: PTCPTH; PTC
JP1: PINHD-1X4; 1X04
LIVE: M01PTH_2MM; 1X01_2MM
NEUTRAL: M01PTH_2MM; 1X01_2MM
R1: 50k; AXIAL-0.3EZ
R2: 10k; AXIAL-0.3EZ
REG_3V3: 7833; TO220-IGO
REG_5V: 7805; TO220-IGO
U$1: FP16-150; FLATPACKXFORMER

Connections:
3V3_REGULATED: C5.1 (+), JP1.3, REG_3V3.OUT
5V_REGULATED: C3.1 (+), JP1.2, REG_5V.OUT
GND: B1.-, C1.-, C3.2 (-), C5.2 (-), JP1.4, R2.P$1 (1), REG_3V3.GND, REG_5V.GND
unnamed: F1.P$1 (1), F2.P$1 (1), U$1.6, U$1.8
unnamed: B1.AC2, F1.P$2 (2), F2.P$2 (2)
unnamed: LIVE.1, U$1.1, U$1.3
unnamed: D1.C, R1.P$2 (2)
unnamed: B1.AC1, D1.A, U$1.5, U$1.7
NEUTRAL_IN: NEUTRAL.1, U$1.2, U$1.4
RAW_VCC: B1.+, C1.+, REG_3V3.IN, REG_5V.IN
VOLTAGE_SENSE: JP1.1, R1.P$1 (1), R2.P$2 (2)

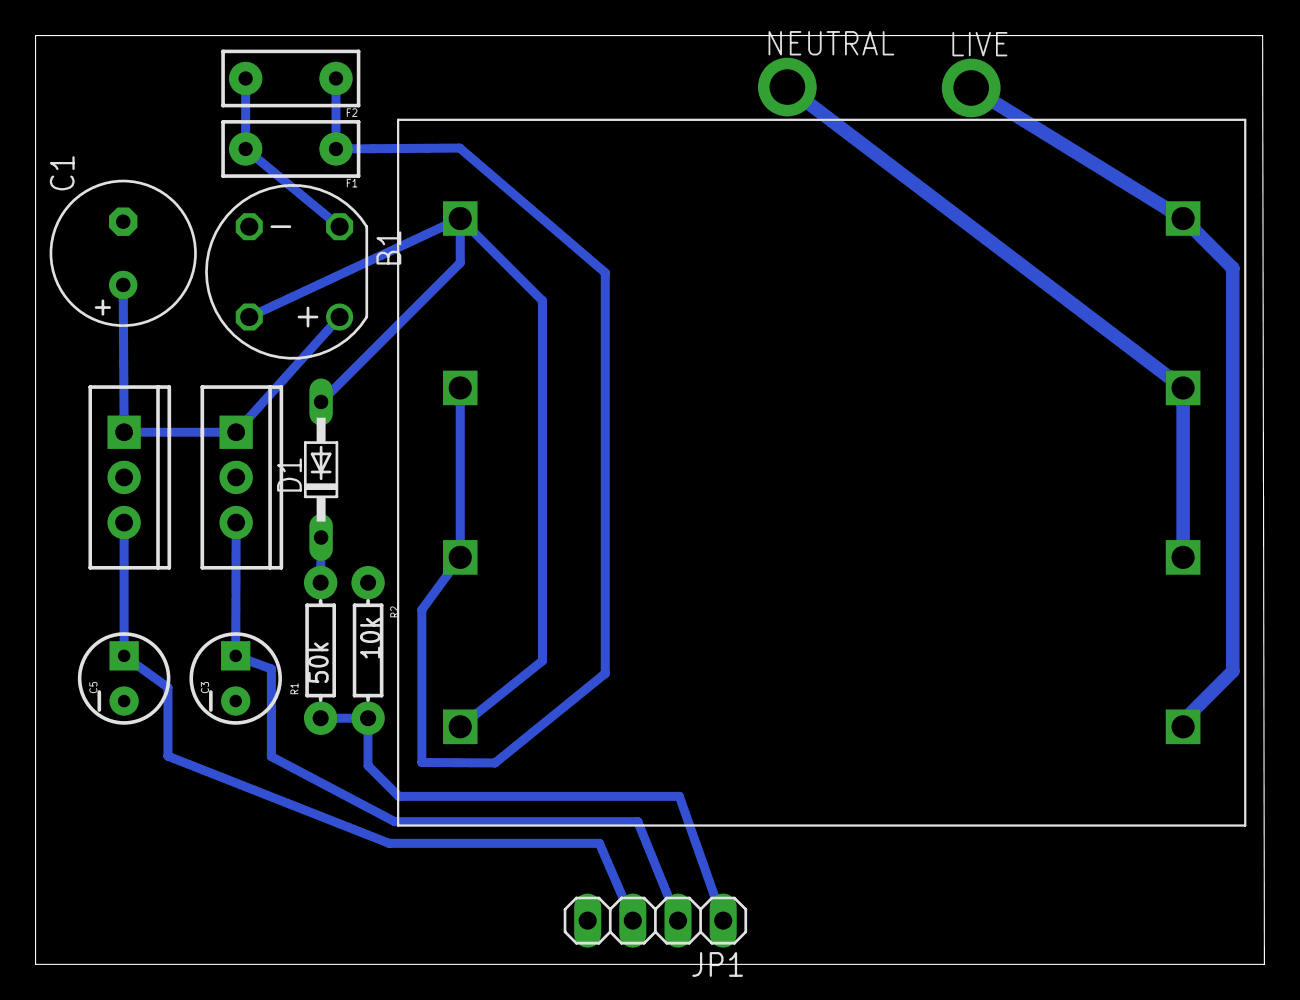
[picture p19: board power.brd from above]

Board: 2 copper layers, 69.1 x 52.2 mm, 15 parts (0 on the bottom side), 11 nets.

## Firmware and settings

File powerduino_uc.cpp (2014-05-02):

#include <LiquidCrystal.h>
#include <Time.h>
#include <SD.h>
#include <stdint.h>
#include <math.h>
#define PCB_LCD_RS 28
#define PCB_LCD_EN 29
#define PCB_LCD_D4 30
#define PCB_LCD_D5 31
#define PCB_LCD_D6 32
#define PCB_LCD_D7 33
#define PCB_BUTTON_1 14
#define PCB_BUTTON_2 15
#define PCB_BUTTON_3 16
#define PCB_BUTTON_4 17
#define PCB_EXT_PIN_0 23
#define PCB_EXT_PIN_1 22
#define PCB_EXT_PIN_2 21
#define PCB_EXT_PIN_3 20
#define PCB_EXT_PIN_4 19
#define PCB_EXT_PIN_5 18
#define PCB_RELAY_PIN_0 6
#define PCB_RELAY_PIN_1 2
#define PCB_RELAY_PIN_2 0
#define PCB_RELAY_PIN_3 27
#define PCB_CURRENT_SENSE_PIN_0 A12
#define PCB_CURRENT_SENSE_PIN_1 A10
#define PCB_CURRENT_SENSE_PIN_2 A11
#define PCB_CURRENT_SENSE_PIN_3 26
#define PCB_VOLTAGE_SENSE_PIN A14
#define SOCKET_ON HIGH
#define SOCKET_OFF LOW
#define MASTER_COMMAND_TRANSMISSION_START 31
#define SLAVE_COMMAND_ACK 30
#define MASTER_COMMAND_TOGGLE_SOCKET 29
#define MASTER_COMMAND_REQUEST_SOCKET_STATUS 28
#define MASTER_COMMAND_SET_TIME 27
#define MASTER_COMMAND_ENERGY_QUERY 26
#define BUF_SIZE 32
#define CLEAR_SEND_BUF() memset(send_buf, 0, BUF_SIZE)
#define CLEAR_RECV_BUF() memset(recv_buf, 0, BUF_SIZE)
#define CLEAR_LCD() lcd.clear()
#define SET_TO_BEGINNING() lcd.setCursor(0, 0)
#define SET_TO_BEGINNING_ROW2() lcd.setCursor(0, 1)
#define SET_TO_BEGINNING_ROW3() lcd.setCursor(0, 2)
#define SET_TO_BEGINNING_ROW4() lcd.setCursor(0, 3)
#define SD_SLAVE_SELECT 10
#define MAINS_VOLTAGE_RMS 120
#define ONE_DAY_IN_SEC 86400
#define KWH_IN_J 3600000
#define ENERGY_LOG_PERIOD_SEC 10
#define UI_BUF_SIZE 25
#define ZERO_CROSS_THRESHOLD 200
#define MENU_PAGE_NUM 4
#define CUSTOM_FUNC_SIZE 3

// button class, supports both click and hold
class button
{
private:
	uint16_t hold_timeout_ms;
	time_t last_press;
	uint8_t pin, state, prev_level, button_pressed, button_released;
public:
	button(uint8_t pin_num, uint8_t button_mode)
	{
		// mode 0 = active low, mode 1 = active high
		button_pressed = button_mode % 2;
		button_released = (button_mode + 1) % 2;
		pin = pin_num;
		pinMode(pin, INPUT);
		prev_level = button_released;
		hold_timeout_ms = 800;
		last_press = 0;
		state = 0;
	}
	
	bool is_pressed()
	{
		return digitalRead(pin) == button_pressed;
	}
	
	void set_hold_timeout_ms(uint16_t timeout)
	{
		hold_timeout_ms = timeout;
	}
	
	uint8_t update()
	{
		uint8_t curr_level = digitalRead(pin);
		if(prev_level == button_released && curr_level == button_pressed) // start timing
		{
			state = 1;
			last_press = millis();
			prev_level = curr_level;
			return 0;
		}
		
		if(state == 1)
		{
			uint32_t duration = millis() - last_press;
			if(curr_level == button_released)
			{
				state = 0;
				prev_level = curr_level;
				if(duration <= 50)
					return 0;
				if(duration > 50 && duration < hold_timeout_ms)
					return 1;
				if(duration >= hold_timeout_ms)
					return 2;
			}
		}
		return 0;
	};

	bool unique_Press()
	{
		return update() == 1;
	}
	bool is_held()
	{
		return update() == 2;
	}
};

// please see the software overview for a detailed
// description of algorithm used here
class current_reader
{
private:
	uint8_t current_sensor_pin[4];
	int16_t sample_array[3][83];
	uint16_t output_buf[3][10];
	uint8_t size, buffer_index;

	void read_current_internal()
	{
		int32_t sqsum[3] = {0,0,0};
		int32_t sum[3] = {0,0,0};
		int16_t avg[3] = {0,0,0};

		buffer_index = ++buffer_index % 10;

		for(int i = 0; i < size; i++)
		{
			for(int j = 0; j < 3; j++)
			{
				sample_array[j][i] = analogRead(current_sensor_pin[j]);
				sum[j] += sample_array[j][i];
			}
			delayMicroseconds(200);
		}

		for(int j = 0; j < 3; j++)
		{
			avg[j] = sum[j] / size;
			for(int i = 0; i < size; i++)
			{
				sample_array[j][i] -= avg[j];
				sqsum[j] += sample_array[j][i] * sample_array[j][i];
			}
		}

		for(int j = 0; j < 3; j++)
		{
			double current = ((((double)4096 + sqrt((double)sqsum[j] / size)) / 8192) * 50 - 25);
			if(j == 0)
                current - 0.06 < 0 ? current = 0 : current -= 0.06;
            current <= 0.06 ? output_buf[j][buffer_index] = 0 : output_buf[j][buffer_index] = current * 1000;
		}
	}

	uint16_t calc_avg(uint16_t *list, uint16_t count)
	{
		int32_t sum = 0;
		for(int i = 0; i < count; i++)
			sum += list[i];
		return sum / count;
	}
public:
	current_reader(uint8_t c1, uint8_t c2, uint8_t c3, uint8_t c4)
	{
		current_sensor_pin[0] = c1;
		current_sensor_pin[1] = c2;
		current_sensor_pin[2] = c3;
		current_sensor_pin[3] = c4;
		size = 83;
		buffer_index = 0;
		for(int i = 0; i < size; i++)
			for(int j = 0; j < 3; j++)
				sample_array[j][i] = 0;

		for(int i = 0; i < 10; i++)
			for(int j = 0; j < 3; j++)
				output_buf[j][i] = 0;
	}

	void read_current(uint16_t current_array[4])
	{
		read_current_internal();
		for(int j = 0; j < 3; j++)
			current_array[j] = calc_avg(output_buf[j], 10);
		current_array[3]= 0;
	}
};

// timer with two operation modes
class timer
{
private:
	bool is_mod;
	uint16_t alert_period;
	time_t last_alert;
	int8_t enabled;
public:
	timer(bool type, uint16_t period)
	{
		is_mod = type;
		alert_period = period;
		if(is_mod)
			last_alert = now();
		else
			last_alert = millis();
		enabled = 1;
	}

	void set_state(int8_t state)
	{
		enabled = state % 2;
	}

	void toggle()
	{
		enabled = ++enabled % 2;
	}

	int8_t is_enabled()
	{
		return enabled;
	}

	bool has_expired()
	{
		if(!enabled)
			return false;
		
		if(is_mod)
		{
			time_t curr_time = now();
			if((curr_time % alert_period == 0) && (curr_time != last_alert))
			{
				last_alert = curr_time;
				return true;
			}
		}
		else
		{
			time_t curr_time = millis();
			if(curr_time - last_alert > alert_period)
			{
				last_alert = curr_time;
				return true;
			}
		}
		return false;
	}
};

// object that holds the value for a setting
class setting
{
private:
	uint8_t size;
	uint8_t curr_val;
public:
	setting(uint8_t s)
	{
		size = s;
		curr_val = 0;
	}
	uint8_t toggle()
	{
		curr_val = ++curr_val % size;
		return curr_val;
	}
	uint8_t get_val()
	{
		return curr_val;
	}
	void set_val(uint8_t val)
	{
		curr_val = val % size;
	}
};

// object that holds a function pointer as well as
// a name, used for user's custom functions
class custom_function_holder
{
private:
	void (*custom_function_ptr)();
	char name[20];
	int8_t enabled;
public:
	custom_function_holder()
	{
		custom_function_ptr = NULL;
		memset(name, 0, 20);
		strcpy(name, "Undefined");
		enabled = 0;
	}
	
	void attach_custom_function(void (*func_ptr)(), char* func_name)
	{
		// assign function pointer
		custom_function_ptr = func_ptr;
		// copy the name for display
		memset(name, 0, 20);
		for(int i = 0; i < 19; i++)
		{
			if(func_name[i] != 0)
				name[i] = func_name[i];
			else
				break;
		}
	}

	void enable()
	{
		enabled = 1;
	}

	void disable()
	{
		enabled = 0;
	}

	void set_state(int8_t state)
	{
		enabled = state % 2;
	}

	void toggle()
	{
		enabled = ++enabled % 2;
	}

	int8_t is_enabled()
	{
		return enabled;
	}
	
	char* get_func_name()
	{
		return name;
	}
	
	void do_custom_function()
	{
		if(custom_function_ptr != NULL && enabled)
			(*custom_function_ptr)();
	}
};


class zero_cross_detector
{
private:
	time_t last_update;
	uint8_t pin, enabled;
	uint16_t last_reading;
	uint16_t zero_cross_threshold;
public:
	zero_cross_detector(uint8_t voltage_sense_pin, uint16_t threshold)
	{
		last_update = micros();
		last_reading = ZERO_CROSS_THRESHOLD + 1;
		pin = voltage_sense_pin;
		zero_cross_threshold = threshold;
		enabled = 1;
	}

	void set_state(int8_t state)
	{
		enabled = state % 2;
	}

	void toggle()
	{
		enabled = ++enabled % 2;
	}

	int8_t is_enabled()
	{
		return enabled;
	}

	// returns 1 if voltage is at a zero crossing going upwards
	// returns 2 if voltage is at a zero crossing going downwards
	// returns 0 if not at a zero crossing
	uint8_t is_zero_cross()
	{
		if(!enabled)
			return 0;

		uint16_t this_reading;
		uint8_t ret = 0;
		// checks every 200 microseconds
		if(micros() - last_update < 200)
			return 0;

		last_update = micros();
		this_reading = analogRead(pin);
		if(last_reading <= zero_cross_threshold && this_reading > zero_cross_threshold)
			ret = 1;
		else if(last_reading >= zero_cross_threshold && this_reading < zero_cross_threshold)
			ret = 2;
	
		last_reading = this_reading;
		return ret;
	}
};

void toggle_socket(uint8_t socket_index, uint8_t socket_state, zero_cross_detector *zcd, uint8_t save_state_to_sd);

uint8_t send_buf[BUF_SIZE];
uint8_t recv_buf[BUF_SIZE];
button button_1(PCB_BUTTON_1, 1);
button button_2(PCB_BUTTON_2, 1);
button button_3(PCB_BUTTON_3, 1);
button button_4(PCB_BUTTON_4, 1);
current_reader c_reader(PCB_CURRENT_SENSE_PIN_0, PCB_CURRENT_SENSE_PIN_1, PCB_CURRENT_SENSE_PIN_2, PCB_CURRENT_SENSE_PIN_3);
timer current_log_timer(true, ENERGY_LOG_PERIOD_SEC);
timer energy_update_timer(false, 3000);
timer UI_update_timer(false, 300);
LiquidCrystal lcd(PCB_LCD_RS, PCB_LCD_EN, PCB_LCD_D4, PCB_LCD_D5, PCB_LCD_D6, PCB_LCD_D7);
setting setting_current_limiter(2);
custom_function_holder custom_func[CUSTOM_FUNC_SIZE];
zero_cross_detector zd(PCB_VOLTAGE_SENSE_PIN, ZERO_CROSS_THRESHOLD);
IntervalTimer current_read_timer;
volatile uint16_t current_array_global[4];

// timer interrupt handler, read current and store them in
// a global current array
void ISR_read_current()
{
	c_reader.read_current((uint16_t*)current_array_global);
}

void setup()
{
	Serial3.begin(9600);
	Serial.begin(9600);
	lcd.begin(20, 4);
	setSyncProvider(getTeensy3Time);
	analogReadResolution(13);
	pinMode(PCB_RELAY_PIN_0, OUTPUT);
	pinMode(PCB_RELAY_PIN_1, OUTPUT);
	pinMode(PCB_RELAY_PIN_2, OUTPUT);
	pinMode(PCB_RELAY_PIN_3, OUTPUT);
	pinMode(PCB_EXT_PIN_0, INPUT);
	pinMode(PCB_EXT_PIN_1, INPUT);
	pinMode(PCB_EXT_PIN_2, INPUT);
	pinMode(PCB_EXT_PIN_3, INPUT);
	pinMode(PCB_EXT_PIN_4, INPUT);
	pinMode(PCB_EXT_PIN_5, INPUT);
	while(!SD.begin(SD_SLAVE_SELECT))
	{
		SET_TO_BEGINNING();
		lcd.print("insert SD card");
	}
	if(recover_state() == -1)
		for(int i; i < 3; i++)
			digitalWrite(get_socket_pin(i), SOCKET_OFF);
	CLEAR_RECV_BUF();
	CLEAR_SEND_BUF();
	custom_func[0].attach_custom_function(demo_auto_lamp, "auto_lamp");
	custom_func[1].attach_custom_function(demo_light_dimmer, "light_dimmer");
	custom_func[2].attach_custom_function(demo_ext_ctrl, "ext_control");
	// the timer interrupt fires every 0.3 seconds to update current reading
	current_read_timer.begin(ISR_read_current, 300000);
	CLEAR_LCD();
	SET_TO_BEGINNING();
}

// custom function of a light dimmer on socket 3
void demo_light_dimmer()
{
	int8_t dimming_delay = 50;
	// turn on zero crossing detector
	zd.set_state(1);
	// turn off interrupts since precise timing is required
	current_read_timer.end();
	noInterrupts();
	CLEAR_LCD();
	print_brightness(dimming_delay);

	while(1)
	{
		// increase brightness when pressing button 1
		if(button_1.unique_Press())
		{
			if(dimming_delay - 10 >= 0)
				dimming_delay -= 10;
			print_brightness(dimming_delay);
			// wait for the next zero crossing
			while(!zd.is_zero_cross());
		}

		// decrease brightness when pressing button 2
		if(button_2.unique_Press())
		{
			if(dimming_delay + 10 < 100)
				dimming_delay += 10;
			print_brightness(dimming_delay);
			while(!zd.is_zero_cross());
		}

		// exit when pressing button 4
		if(button_4.unique_Press())
		{
			// restart timer interrupt and other interrupts
			current_read_timer.begin(ISR_read_current, 300000);
			interrupts();
			custom_func[1].disable();
			return;
		}

		if(zd.is_zero_cross())
		{
			// if at full brightness, just turn it on
			if(dimming_delay == 0)
			{
				digitalWrite(PCB_RELAY_PIN_2, SOCKET_ON);
				continue;
			}
			delayMicroseconds(dimming_delay * 80);
			digitalWrite(PCB_RELAY_PIN_2, SOCKET_ON);
			delayMicroseconds(200);
			digitalWrite(PCB_RELAY_PIN_2, SOCKET_OFF);
		}
	}
}

void print_brightness(int8_t dimming_delay)
{
	SET_TO_BEGINNING();
	lcd.print("brightness: ");
	lcd.print((int)(100 - dimming_delay));
	lcd.print("  ");
}

// a custom function that let another device take over
// control of the power strip, sockets are controlled by
// 3 external pins
void demo_ext_ctrl()
{
	digitalWrite(PCB_RELAY_PIN_0, digitalRead(PCB_EXT_PIN_0));
	digitalWrite(PCB_RELAY_PIN_1, digitalRead(PCB_EXT_PIN_1));
	digitalWrite(PCB_RELAY_PIN_2, digitalRead(PCB_EXT_PIN_2));
}

void loop()
{
	// execute command from PC if available
	if(get_serial_commands())
	{
		uint8_t master_command = recv_buf[0];
		switch(master_command)
		{
			case MASTER_COMMAND_TOGGLE_SOCKET:
			toggle_socket(recv_buf[1], recv_buf[2], &zd, 1);
			send_default_ACK();
			break;
				
			case MASTER_COMMAND_REQUEST_SOCKET_STATUS:
			send_socket_status();
			break;

			case MASTER_COMMAND_SET_TIME:
			Teensy3Clock.set(char_to_int32(recv_buf+1));
			setTime(Teensy3Clock.get());
			send_default_ACK();
			break;
				
			case MASTER_COMMAND_ENERGY_QUERY:
			send_energy(char_to_int32(recv_buf + 1), char_to_int32(recv_buf + 5));
			break;
		}
	}
	
	print_UI();

	// execute custom functions, if they're enabled
	for(int i = 0; i < CUSTOM_FUNC_SIZE; i++)
		custom_func[i].do_custom_function();

	// execute current limiter, if they're enabled
	if(setting_current_limiter.get_val())
		limit_current(5000);

	// store current reading to SD card for energy logging
	if(current_log_timer.has_expired())
		append_current_log(getTeensy3Time(), (uint16_t*)current_array_global);
}

// unfinished :(
void limit_current(int limit_mA)
{
	;
}

// read a light sensor on PCB_EXT_PIN_5, turn
// socket 1 on if dark, on otherwise.
void demo_auto_lamp()
{
	if(analogRead(PCB_EXT_PIN_5) > 1000)
		digitalWrite(PCB_RELAY_PIN_0, SOCKET_OFF);
	else
		digitalWrite(PCB_RELAY_PIN_0, SOCKET_ON);
}

void print_UI()
{
	// press button 4 to change pages
	static uint8_t page = 0;
	if(button_4.unique_Press())
	{
		CLEAR_LCD();
		page = (page + 1) % MENU_PAGE_NUM;
	}
	switch(page)
	{
		case 0:
			SET_TO_BEGINNING();
			lcd.print("Sockets:");
			// first 3 sockets controlled by button press of first 3 buttons
			if(button_1.unique_Press())
				toggle_socket(0, !digitalRead(get_socket_pin(0)), &zd, 1);
			if(button_2.unique_Press())
				toggle_socket(1, !digitalRead(get_socket_pin(1)), &zd, 1);
			if(button_3.unique_Press())
				toggle_socket(2, !digitalRead(get_socket_pin(2)), &zd, 1);
			if(UI_update_timer.has_expired())
			{
				char message[UI_BUF_SIZE];
				for(int i = 0; i < 3; i++)
				{
					make_message(message, i, digitalRead(get_socket_pin(i)), (double)current_array_global[i] / 1000);
					lcd.setCursor(0, i+1);
					lcd.print(message);
				}
			}
			break;
			
		case 1:
			SET_TO_BEGINNING();
			lcd.print("Energy Today:");
			print_time();
			if(energy_update_timer.has_expired())
			{
				uint32_t result[4];
				char message[21];
				calc_energy(now() - ONE_DAY_IN_SEC, now(), result);
				sprintf(message, "1:%.2fkWh 2:%.2fkWh", (double)result[0] / KWH_IN_J, (double)result[1] / KWH_IN_J);
				SET_TO_BEGINNING_ROW2();
				lcd.print(message);
				sprintf(message, "3:%.2fkWh T:%.2fkWh", (double)result[2] / KWH_IN_J, (double)(result[0]+result[1]+result[2]) / KWH_IN_J);
				SET_TO_BEGINNING_ROW3();
				lcd.print(message);
			}
			break;
			
		case 2:
			SET_TO_BEGINNING();
			lcd.print("Custom Programs:");
			if(button_1.unique_Press())
				custom_func[0].toggle();
			if(button_2.unique_Press())
				custom_func[1].toggle();
			if(button_3.unique_Press())
				custom_func[2].toggle();

			for(int i = 0; i < CUSTOM_FUNC_SIZE; i++)
			{
				lcd.setCursor(0, i+1);
				lcd.print(custom_func[i].get_func_name());
				lcd.setCursor(17, i+1);
				if(custom_func[i].is_enabled())
					lcd.print("ON ");
				else
					lcd.print("OFF");
			}
			break;
			
		case 3:
			SET_TO_BEGINNING();
			lcd.print("Settings:");
			// save settings to SD card
			save_state();
			if(button_1.unique_Press())
				current_log_timer.toggle();
			
			if(button_2.unique_Press())
				zd.toggle();

			if(button_3.unique_Press())
				setting_current_limiter.toggle();
			
			SET_TO_BEGINNING_ROW2();
			lcd.print("Log energy: ");
			lcd.setCursor(17, 1);
			if(current_log_timer.is_enabled())
				lcd.print("ON ");
			else
				lcd.print("OFF");

			SET_TO_BEGINNING_ROW3();
			lcd.print("0-cross toggle: ");
			lcd.setCursor(17, 2);
			if(zd.is_enabled())
				lcd.print("ON ");
			else
				lcd.print("OFF");

			SET_TO_BEGINNING_ROW4();
			lcd.print("current limiter: ");
			lcd.setCursor(17, 3);
			if(setting_current_limiter.get_val() == 1)
				lcd.print("ON ");
			else
				lcd.print("OFF");
			break;
			
		default:
			CLEAR_LCD();
			SET_TO_BEGINNING();
			lcd.print("unknown page");
	}
}

void print_time()
{
	SET_TO_BEGINNING_ROW4();
	time_t local_time = now() - 18000;
	lcd.print(year(local_time));
	lcd.print("-");
	lcd.print(month(local_time));
	lcd.print("-");
	lcd.print(day(local_time));
	lcd.print(" ");
	lcd.print(hour(local_time));
	lcd.print(":");
	lcd.print(minute(local_time));
	lcd.print(":");
	lcd.print(second(local_time));
	lcd.print("  ");
}

void make_message(char* message, uint8_t socket_index, uint8_t socket_status, double socket_current)
{
	memset(message, 0, UI_BUF_SIZE);
	sprintf(message, "S%d: ", socket_index + 1);
	if(socket_status == 1)
		sprintf(message + 4, "ON");
	else
	{
		sprintf(message + 4, "OFF             ");
		return;
	}
	if(socket_current > 1)
		sprintf(message + 8, "%.1fA", socket_current);
	else
		sprintf(message + 8, "%.2fA", socket_current);
	double power = socket_current * MAINS_VOLTAGE_RMS;
	if(power > 100)
		sprintf(message + 14, "%.0fW", power);
	else
		sprintf(message + 14, "%.2fW", power);
	for(int i = 0; i < 20; i++)
		message[i] == 0 ? message[i] = ' ' : message[i];
	for(int i = 20; i < 25; i++)
		message[i] = 0;
}

// send out energy consumption of all sockets
// over serial in response of PC's command
void send_energy(time_t start_utc, time_t end_utc)
{
	CLEAR_SEND_BUF();
	uint32_t result[4];
	calc_energy(start_utc, end_utc, result);
	send_buf[0] = SLAVE_COMMAND_ACK;
	send_buf[1] = 16; // 16 bytes of data
	for(int i = 0; i < 4; i++)
		int32_to_char(result[i], &send_buf[2 + 4 * i]);
	Serial3.write(send_buf, 18);
}

// calculates how much energy was used by all sockets, stores the 
// result in result[4], unit is in Joules
void calc_energy(time_t start_utc, time_t end_utc, uint32_t result[4])
{
	if(start_utc > end_utc)
		return;
	
	time_t start_day = get_start_of_day(start_utc);
	time_t current_timestamp, last_timestamp;
	uint16_t current_array[4];
	// how many days between start and end
	uint16_t span = ((get_start_of_day(end_utc) - start_day) / ONE_DAY_IN_SEC) + 1;
	char file_name[10];
	File log_file;
	
	for(int i = 0; i < 4; i++)
		result[i] = 0;
	// for each day between start and end
	for(int i = 0; i < span; i++)
	{
		// look for that day's file, it doesn't exist go to next day
		get_filename(start_day + i * ONE_DAY_IN_SEC, file_name);
		if(!SD.exists(file_name))
			continue;
		
		log_file = SD.open(file_name, FILE_READ);
		if(log_file == NULL)
		{
			CLEAR_LCD();
			SET_TO_BEGINNING();
			lcd.print("cannot read log file");
			delay(1000);
			return;
		}
		
		// after the file is found, go to the first entry after start_utc
		while(1)
		{
			if(read_current_log_entry(&log_file, &current_timestamp, current_array) == -1)
				goto next_file;
			if(current_timestamp >= start_utc)
				break;
		}
		// now we're at the start
		last_timestamp = current_timestamp;
		while(read_current_log_entry(&log_file, &current_timestamp, current_array) != -1)
		{
			if(current_timestamp >= end_utc)
				goto calc_energy_finish;
			// sum up the current reading for integration
			if(current_timestamp - last_timestamp <= ENERGY_LOG_PERIOD_SEC)
				for(int j = 0; j < 4; j++)
					result[j] += current_array[j];
			last_timestamp = current_timestamp;
		}
	next_file:
		log_file.close();
	}
calc_energy_finish:
	// Energy = power * time = current * 120V * time
	for(int j = 0; j < 4; j++)
		result[j] = (uint32_t)(((double)result[j] / 1000) * MAINS_VOLTAGE_RMS * ENERGY_LOG_PERIOD_SEC);
}

// read a current log entry from the log file(at its current position)
// fills up timestamp with the timestamp of that entry, and current_array with
// the current reading of that entry, returns -1 if eof is reached.
int8_t read_current_log_entry(File *log_file, time_t *timestamp, uint16_t *current_array)
{
	// copy an entry to read_buf
	uint8_t read_buf[12];
	for(int i = 0; i < 12; i++)
	{
		if(!log_file->available())
			return -1;
		read_buf[i] = log_file->read();
	}
	*timestamp = char_to_int32(read_buf);
	for(int i = 0; i < 4; i++)
		current_array[i] = char_to_int16(&read_buf[4 + 2*i]);
	return 0;
}

time_t get_start_of_day(time_t time)
{
	TimeElements tm;
	tm.Second = 0;
	tm.Minute = 0;
	tm.Hour = 0;
	tm.Wday = 0;
	tm.Day = day(time);
	tm.Month = month(time);
	tm.Year = year(time) - 1970;
	return makeTime(tm);
}

void get_filename(time_t time, char buf[10])
{
	memset(buf, 0, 10);
	sprintf(buf, "%d%02d%02d", year(time), month(time), day(time));
}

void append_current_log(time_t time, uint16_t current_array[4])
{
	// each entry: time_t current1 current2 current3 current4
	File log_file;
	char file_name[10];
	get_filename(time, file_name);
	log_file = SD.open(file_name, FILE_WRITE);
	if(log_file == NULL)
	{
		CLEAR_LCD();
		SET_TO_BEGINNING();
		lcd.print("cannot write log file");
		delay(100);
		return;
	}
	uint8_t write_buf[12];
	// first 4 bytes is timestamp
	int32_to_char(time, &write_buf[0]);
	// then 2 * 4 bytes of current reading
	for(int i = 0; i < 4; i++)
		int16_to_char(current_array[i], &write_buf[4 + 2*i]);
	// write them into sd card
	log_file.write(write_buf, 12);
	log_file.close();
}
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

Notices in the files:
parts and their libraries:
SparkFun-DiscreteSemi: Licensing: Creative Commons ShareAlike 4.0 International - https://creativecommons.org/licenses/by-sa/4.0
